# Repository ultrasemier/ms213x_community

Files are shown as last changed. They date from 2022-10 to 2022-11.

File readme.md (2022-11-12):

# MS2130 MS2131 Reference Design

## HardWare
  LCEDA

  MS2130
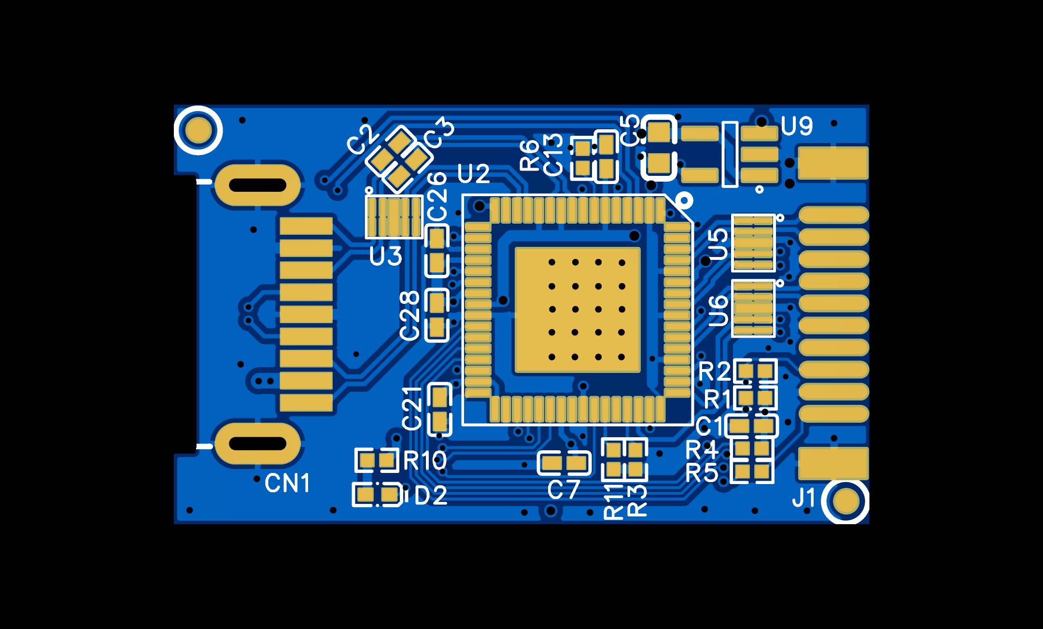
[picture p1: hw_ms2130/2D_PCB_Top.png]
MS2130 top
  
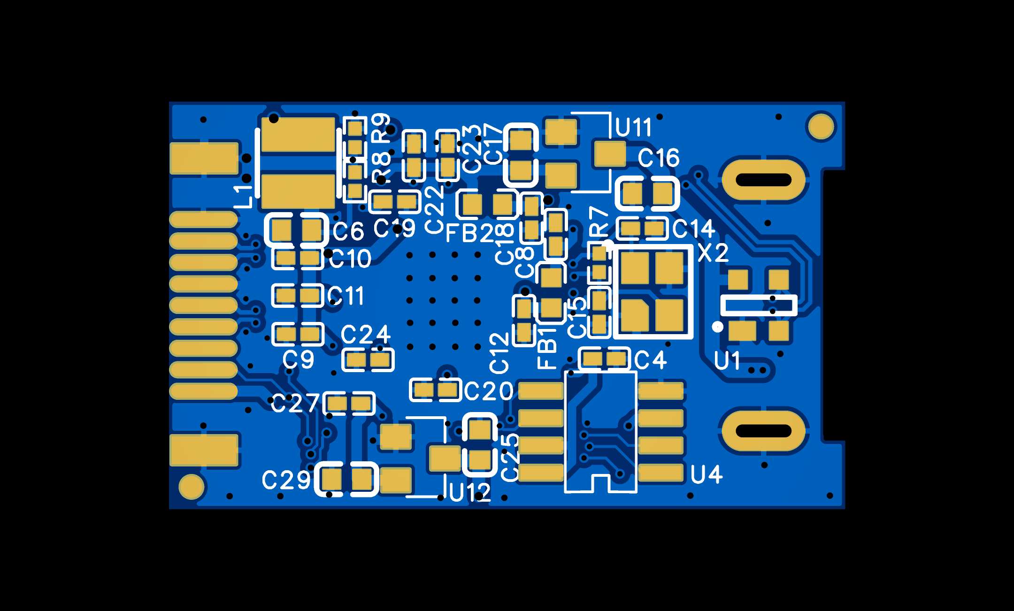
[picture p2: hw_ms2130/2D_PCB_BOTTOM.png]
MS2130 bottom
  
  MS2131
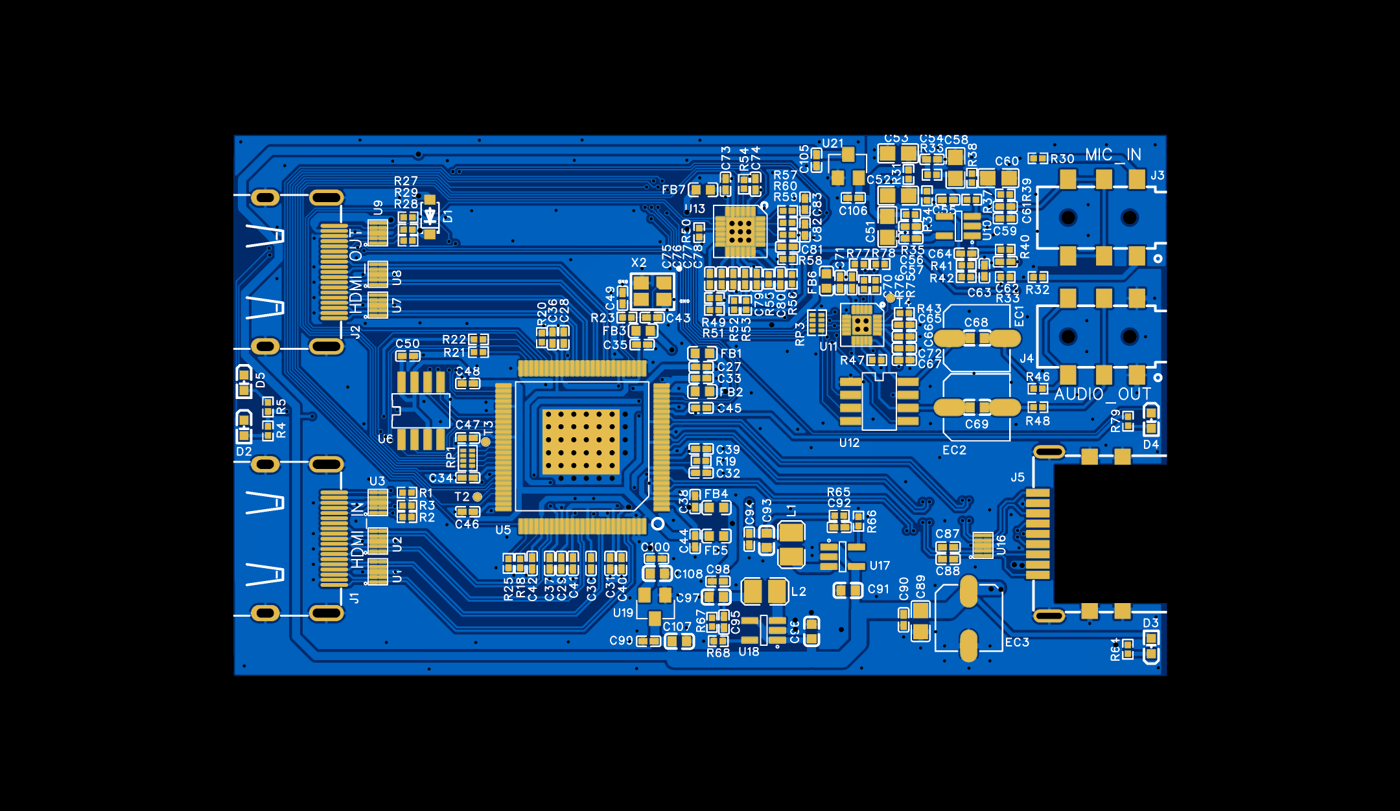
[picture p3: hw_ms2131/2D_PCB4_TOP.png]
MS2131 top
  
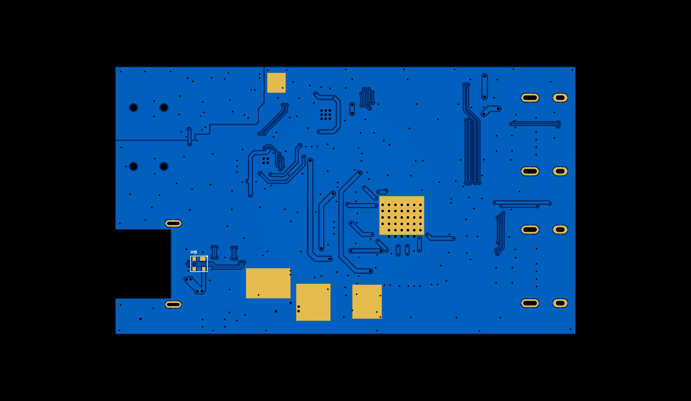
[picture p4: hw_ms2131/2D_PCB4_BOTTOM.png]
MS2131 bottom
  

## FirmWare
  [MS2130_sample_20221026](firmware/MS2130_sample_20221026.bin)
## Doc
  [MS2130 DS](doc/ms2130_ds.md)
## PCTool

## User Data

| ROM Address | Flash Address | Length  | User Data | data type |
|--- |--- |--- |--- | --- |
| 0x00F800 | 0x00F830 | 0x100 |edid | uint8 array[256] |
| 0x00F900 | 0x00F930 | 0x120 |hdcpUserKey | uint8 array[288] |
| 0x00FA20 | 0x00FA50 | 0x020 |ultrasemi | uchar array[32]  |
| 0x00FA40 | 0x00FA70 | 0x020 |ultrasemi_version | uchar array[32]  |
| 0x00FA60 | 0x00FA90 | 0x020 |ultrasemi_magic | uint8 array[32]  |
| 0x00FA80 | 0x00FAB0 | 0x020 |ManufacturerString  | user_string_t |
| 0x00FAA0 | 0x00FAD0 | 0x020 |ProduceString | user_string_t |
| 0x00FAC0 | 0x00FAF0 | 0x020 |U2ProduceString | user_string_t |
| 0x00FAE0 | 0x00FB10 | 0x020 |AudioString | user_string_t |
| 0x00FB00 | 0x00FB30 | 0x020 |U2AudioString | user_string_t |
| 0x00FB20 | 0x00FB50 | 0x020 |SerialnumString | user_string_t |
| 0x00FB40 | 0x00FB70 | 0x020 |U2SerialnumString | user_string_t |
| 0x00FB60 | 0x00FB90 | 0x020 |BCSH | user_bcsh_t |
| 0x00FB80 | 0x00FBB0 | 0x020 |AudioRoute | audio_route_t |

### user_string_t

* [Offset 0] length : uint8
  + 2 ~ 31
* [Offset 1:31] char array : uchar
  
### user_bcsh_t

  | Index | data type | data name |---              |
  |---    |---        |---        |---              |
  | 0     | UINT8     | bcsh_en   |0x01: User BCSH data Enable<br>other: User BCSH data Disable|
  | 1     | INT8      | b         | -127 ~ 128      |
  | 2     | UINT8     | c         | 0 ~ 255         |
  | 3     | UINT8     | s         | 0 ~ 255         |
  | 3     | INT8      | h         | -127 ~ 128      |
  
### audio_route_t

* [Offset 0] sample_rate : UINT8
  + 0 : AUDIO_SR_48000
  + 1 : AUDIO_SR_96000
  + other : Not used
* [Offset 1] i2s_in_mode : UINT8
  + 0 : slave
  + 1 : master
  + other : Not used
* [Offset 2] mix3_mode : UINT8
  + 1 : HDMI RX
  + 2 : I2S1 IN
  + 3 : I2S1 IN & HDMI RX
  + 4 : I2S2
  + 5 : I2S2 IN & HDMI RX
  + 6 : I2S1 IN & I2S2 IN
  + 7 : I2S1 IN & I2S2 IN & HDMI RX
  + other : Not used
* [Offset 3] i2s1_mode : UINT8
  + 9  : HDMI RX
  + 10 : MIX3 & USB OUT
  + 11 : MIX3
  + 12 : USB OUT
  + other : Not used
* [Offset 4] usb_out_mute : UINT8
  + 0 : unmute
  + 1 : mute
  + other : Not used
* [Offset 5] lk621_en : UINT8
  + 0x00 : none
  + 0x01 : config lk621 @0x26
  + 0x02 : config lk621 @0x20
  + 0x03 : config lk621 both
  + other : Not used

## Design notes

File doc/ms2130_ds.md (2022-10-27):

# MS2130 - USB3.0 高清视频采集芯片

## (非官方文档)

### 1.基本介绍

MS2130 是一款 USB 3.0 高清视频和音频采集芯片，内部集成 USB3.0 Device 控制器、数据收发模块、音视频处理模块。MS2130 可以通过 USB 3.0 接口将 HDMI 输入的音视频信号传送到 PC、智能手机、平板电脑上预览或采集。MS2130 输出支特 YUV422 和 MJPEG 两种模式，兼容 Windows、Android 和Mac OS 系统。

||MS2109|	MS2130|
|--- |---|---|
|USB  版本 |	2.0	|3.2 Gen1|
|USB 速率	 |480Mbps	|5Gbps|
|1080P@30 MJPEG	  |支持	|支持|
|1080P@60 MJPEG	  |不支持	|支持|
|1080P@30 YUV422	|不支持	|支持|
|1080P@60 YUV422	|不支持	|支持|
|典型延时	 |80ms	|50ms

### 2.功能特征

* HDMI RX
  * HDMI 1.4b 兼容
  * 支持 DVI 1.0
  * 支持 HDCP 1.4
  * 支持 RGB444、YCBCR422、YCBCR444、YCBCR420
  * 支持 deep color 24/30/36 位模式
  * 支持 CEA-861-E/CEA-861-F 视频格式
  * 最大输入分辨率 4K(3840×2160@30Hz)
  
* USB 3.0
  * 集成 USB 3.0 Device
  * 兼容 USB 2.0 Device 模式
  * USB 视频符合 UVC 1.0 协议
  * USB 音频符合 UAC 1.0 协议
  * USB 视频输出支持 YUV422 和 MJPEG 两种模式

* USB 视频输出分辨率
  * 默认最大分辨率1920×1080@60Hz
  
* 操作系统支持
  * Windows XP/7/8/10
  * Andriod 5.0 或以上
  * MacOS
  * Linux
  * 其他支持UVC的系统
  
* 时钟处理
  * 外接 24MHz 无源晶振
  * 内建 PLL 电路

* 复位
  * 内建上电复位电路

* 封装
  * QFN-64塑封（9mm×9mm)
  * 无铅，符合RoHS标准

### 3.功能框图

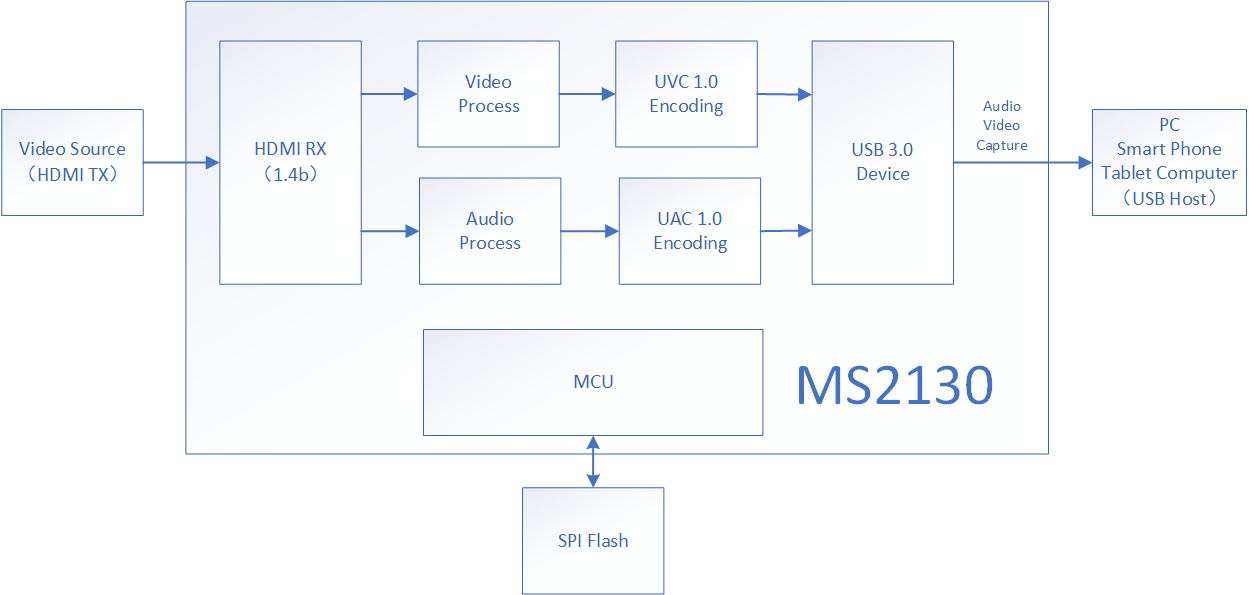
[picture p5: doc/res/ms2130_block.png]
  

### 4.功能描述

* **GPIO**
  
  MS2130有6个可编程GPIO,可通过软件自定义功能。

* **HDMI RX EDID描述**
  
  |类别|描述|
  |---|---|
  |显示名称|HDMI TO USB|
  |最佳分辨率1|4K@30Hz,297MHz|
  |最佳分辨率2|1080P@60Hz,148.5MHz|
  |视频支持分辨率列表|640×480@60Hz<br>800×600@60Hz<br>1024×768@60Hz<br>1152×864@60Hz<br>1280×720@60Hz<br>1280×800@60Hz<br>1280×960@60Hz<br>1280×1024@60Hz<br>1440×900@60Hz<br>1600×900@60Hz<br>1680×1050@60Hz<br>1920×1080@60Hz<br>3840×2160@30Hz<br>4096×2160@30Hz|
  |视频色彩空间支持|RGB,YUV444,LYUV422,YUV420|
  |Deep color支持| 30bits,36bits|
  |音频格式支持|格式：L-PCM<br>采样率：32KHz,44.1KHz,48KHz<br>通道数：最大两通道<br>位数：16bit,20bit,24bit

* **USB 视频输出**
  
  MS2130支持USB3.0&USB2.0模式视频采集，符合UVC1.0协议，支持YUV422和MJPEG两种格式视频输出，默认最大输出分辨率1920×1080@60Hz。
  MS2130USB默认输出分辨率列表如下，可以通过修改软件配置，由用户自定义输出分辨率(最大可支持到4K@15Hz)。

  <table>
    <tr>
      <td >USB 模式</td>
      <td>YUV422</td>
      <td>MJPEG</td>
    </tr>
    <tr>
      <td rowspan="11">USB 3.0 模式</td>
      <td>1920×1080@60Hz/50Hz/30Hz/20Hz/10Hz</td>
      <td>1920×1080@60HZ/50Hz/30Hz/20Hz/10Hz</td>
    </tr>
    <tr>
      <td>1600×1200@60Hz/50Hz/30Hz/20Hz/10Hz</td>
      <td>1600×1200@60Hz/50Hz/30Hz/20Hz/10Hz</td>
    </tr>
    <tr>
      <td>1360×  768@60Hz/50Hz/30Hz/20Hz/10Hz</td>
      <td>1360×  768@60Hz/50Hz/30Hz/20Hz/10Hz</td>
    </tr>
    <tr>
      <td>1280×1024@60Hz/50Hz/30Hz/20Hz/10Hz</td>
      <td>1280×1024@60Hz/50Hz/30Hz/20Hz/10Hz</td>
    </tr>
    <tr>
      <td>1280×  960@60Hz/50Hz/30Hz/20Hz/10Hz</td>
      <td>1280×  960@60Hz/50Hz/30Hz/20Hz/10Hz</td>
    </tr>
    <tr>
      <td>1280×  720@60Hz/50Hz/30Hz/20Hz/10Hz</td>
      <td>1280×  720@60Hz/50Hz/30Hz/20Hz/10Hz</td>
    </tr>
    <tr>
      <td>1024×  768@60Hz/50Hz/30Hz/20Hz/10Hz</td>
      <td>1024×  768@60Hz/50Hz/30Hz/20Hz/10Hz</td>
    </tr>
    <tr>
      <td>  800×  600@60Hz/50Hz/30Hz/20Hz/10Hz</td>
      <td>  800×  600@60Hz/50Hz/30Hz/20Hz/10Hz</td>
    </tr>
    <tr>
      <td>  720×  576@60Hz/50Hz/30Hz/20Hz/10Hz</td>
      <td>  720×  576@60Hz/50Hz/30Hz/20Hz/10Hz</td>
    </tr>
    <tr>
      <td>  720×  480@60Hz/50Hz/30Hz/20Hz/10Hz</td>
      <td>  720×  480@60Hz/50Hz/30Hz/20Hz/10Hz</td>
    </tr>
    <tr>
      <td>  640×  480@60Hz/50Hz/30Hz/20Hz/10Hz</td>
      <td>  640×  480@60Hz/50Hz/30Hz/20Hz/10Hz</td>
    </tr>
    <tr>
      <td rowspan="11">USB 2.0 模式</td>
      <td>1920×1080@10Hz/5Hz</td>
      <td>1920×1080@50Hz/30Hz/25Hz/20Hz/10Hz</td>
    </tr>
    <tr>
      <td>1600×1200@10Hz/5Hz</td>
      <td>1600×1200@60Hz/50Hz/30Hz/20Hz/10Hz</td>
    </tr>
    <tr>
      <td>1360×  768@15Hz/8Hz</td>
      <td>1360×  768@60Hz/50Hz/30Hz/20Hz/10Hz</td>
    </tr>
    <tr>
      <td>1280×1024@15Hz/8Hz</td>
      <td>1280×1024@60Hz/50Hz/30Hz/20Hz/10Hz</td>
    </tr>
    <tr>
      <td>1280×  960@15Hz/8Hz</td>
      <td>1280×  960@60Hz/50Hz/30Hz/20Hz/10Hz</td>
    </tr>
    <tr>
      <td>1024×  768@20Hz/10Hz</td>
      <td>1024×  768@60Hz/50Hz/30Hz/20Hz/10Hz</td>
    </tr>
    <tr>
      <td>  800×  600@30Hz/20Hz/10Hz</td>
      <td>  800×  600@60Hz/50Hz/30Hz/20Hz/10Hz</td>
    </tr>
    <tr>
      <td>  720×  576@60Hz/25Hz/20Hz/10Hz</td>
      <td>  720×  576@60Hz/50Hz/30Hz/20Hz/10Hz</td>
    </tr>
    <tr>
      <td>  720×  480@60Hz/30Hz/20Hz/10Hz</td>
      <td>  720×  480@60Hz/50Hz/30Hz/20Hz/10Hz</td>
    </tr>
    <tr>
      <td>  640×  480@60Hz/30Hz/20Hz/10Hz</td>
      <td>  640×  480@60Hz/50Hz/30Hz/20Hz/10Hz</td>
    </tr>
  </table>

* **USB 音频输出**
  
  MS2130 USB音频符合UAC1.0协议，默认输出为48KHz立体声，可通过软件配置实现其它分辨率音频输出。

### 5.引脚
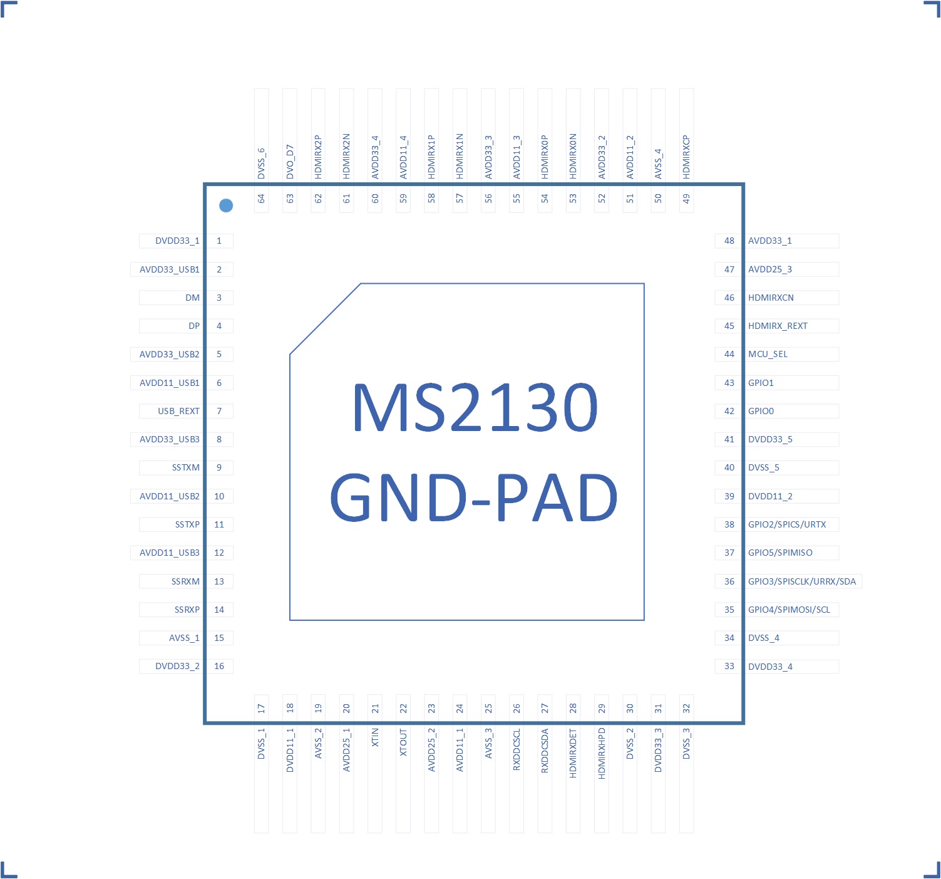
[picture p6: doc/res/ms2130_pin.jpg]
  

### 6.引脚描述

  <table>
    <tr>
      <td>引脚名称</td>
      <td>引脚#</td>
      <td>类型</td>
      <td>描述</td>
    </tr>
    <tr>
      <td colspan="4">通用IO</td>
    </tr>
    <tr>
      <td>GPIO0</td>
      <td>42</td>
      <td>数字输入/输出</td>
      <td>通用数字IO</td>
    </tr>
    <tr>
      <td>GPIO1</td>
      <td>43</td>
      <td>数字输入/输出</td>
      <td>通用数字IO</td>
    </tr>
    <tr>
      <td>GPIO2/SPICS/URTX</td>
      <td>38</td>
      <td>数字输入/输出</td>
      <td>通用数字IO,复用SPI Master接口CSPN和UART TX PIN;<br>如果外围连接了SPI接口Flash,芯片上电后会自动配置为SPICS功能</td>
    </tr>
    <tr>
      <td>GPIO3/SPISCLK/URRX/SDA</td>
      <td>36</td>
      <td>数字输入/输出</td>
      <td>通用数字IO,复用SPI Master接口SCLK PIN、UART RX PIN和I2C Master SDA PIN;<br>如果外围连接了SPI接口Flash,芯片上电后会自动配置为SPISCLK功能</td>
    </tr>
    <tr>
      <td>GPIO4/SPIMOSI/SCL</td>
      <td>35</td>
      <td>数字输入/输出</td>
      <td>通用数字IO,复用SPI Master接口MOSI PIN和I2C Master SCL PIN;<br>如果外围连接了SPI接口Flash,芯片上电后会自动配置为SPIMOSI功能</td>
    </tr>
    <tr>
      <td>GPIO5/SPIMISO</td>
      <td>37</td>
      <td>数字输入/输出</td>
      <td>通用数字IO,复用SPI Master接口MISO PIN;<br>如果外围连接了SPI接口Flash,芯片上电后会自动配置为SPI MISO功能</td>
    </tr>
    <tr>
      <td colspan="4">USB</td>
    </tr>
    <tr>
      <td>DP</td>
      <td>4</td>
      <td>数字输入/输出</td>
      <td>USB2.0差分正端信号</td>
    </tr>
    <tr>
      <td>DM</td>
      <td>3</td>
      <td>数字输入/输出</td>
      <td>USB2.0差分负端信号</td>
    </tr>
    <tr>
      <td>USB REXT</td>
      <td>7</td>
      <td>数字输出</td>
      <td>接200欧电阻到地</td>
    </tr>
    <tr>
      <td>SSTXP</td>
      <td>11</td>
      <td>数字输出</td>
      <td>USB3.0差分输出正端信号</td>
    </tr>
    <tr>
      <td>SSTXM</td>
      <td>9</td>
      <td>数字输出</td>
      <td>USB3.0差分输出负端信号</td>
    </tr>
    <tr>
      <td>SSRXP</td>
      <td>14</td>
      <td>数字输入</td>
      <td>USB3.0差分输入正端信号</td>
    </tr>
    <tr>
      <td>SSRXM</td>
      <td>13</td>
      <td>数字输入</td>
      <td>USB3.0差分输入负端信号</td>
    </tr>
    <tr>
      <td colspan="4">HDMI RX</td>
    </tr>
    <tr>
      <td>HDMIRXCN</td>
      <td>46</td>
      <td>数字输入</td>
      <td>HDMI接收端差分时钟输入负端信号</td>
    </tr>
    <tr>
      <td>HDMIRXCP</td>
      <td>49</td>
      <td>数字输入</td>
      <td>HDMI接收端差分时钟输入正端信号</td>
    </tr>
    <tr>
      <td>HDMIRX0N</td>
      <td>53</td>
      <td>数字输入</td>
      <td>HDMI接收端差分通道0数据输入负端信号</td>
    </tr>
    <tr>
      <td>HDMIRX0P</td>
      <td>54</td>
      <td>数字输入</td>
      <td>HDMI接收端差分通道0数据输入正端信号</td>
    </tr>
    <tr>
      <td>HDMIRX1N</td>
      <td>57</td>
      <td>数字输入</td>
      <td>HDMI接收端差分通道1数据输入负端信号</td>
    </tr>
    <tr>
      <td>HDMIRX1P</td>
      <td>58</td>
      <td>数字输入</td>
      <td>HDMI接收端差分通道1数据输入正端信号</td>
    </tr>
    <tr>
      <td>HDMIRX2N</td>
      <td>61</td>
      <td>数字输入</td>
      <td>HDMI接收端差分通道2数据输入负端信号</td>
    </tr>
    <tr>
      <td>HDMIRX2P</td>
      <td>62</td>
      <td>数字输入</td>
      <td>HDMI接收端差分通道2数据输入正端信号</td>
    </tr>
    <tr>
      <td>HDMIRX_REXT</td>
      <td>45</td>
      <td>模拟输出</td>
      <td>连接一个1.6k电阻到地</td>
    </tr>
    <tr>
      <td>HDMIRXHPD</td>
      <td>29</td>
      <td>数字输出</td>
      <td>HDMI接收端热插拔信号输出</td>
    </tr>
    <tr>
      <td>HDMIRXDET</td>
      <td>28</td>
      <td>数字输入</td>
      <td>HDMI接收端5V输入检测</td>
    </tr>
    <tr>
      <td>RXDDCSDA</td>
      <td>27</td>
      <td>数字输入/输出</td>
      <td>HDMI接收端显示数据通道串行数据总线</td>
    </tr>
    <tr>
      <td>RXDDCSCL</td>
      <td>26</td>
      <td>数字输入</td>
      <td>HDMI接收端显示数据通道串行时钟总线</td>
    </tr>
    <tr>
      <td colspan = "4">调试 PIN</td>
    </tr>
    <tr>
      <td>MCU_SEL</td>
      <td>44</td>
      <td>数字输入</td>
      <td>调试PIN，默认浮空</td>
    </tr>
    <tr>
      <td>DVO_D7</td>
      <td>63</td>
      <td>数字输出</td>
      <td>调试PIN，默认浮空</td>
    </tr>
    <tr>
      <td colspan="4">晶振</td>
    </tr>
    <tr>
      <td>XTIN</td>
      <td>21</td>
      <td>模拟输入</td>
      <td>接24MHz无源晶振输入</td>
    </tr>
    <tr>
      <td>XTOUT</td>
      <td>22</td>
      <td>模拟输出</td>
      <td>接24MHz无源晶振输出</td>
    </tr>
    <tr>
      <td colspan = "4">系统电源和地</td>
    </tr>
    <tr>
      <td>AVDD33_USB1~3</td>
      <td>2,5,8</td>
      <td>电源</td>
      <td>USB模块3.3V供电</td>
    </tr>
    <tr>
      <td>AVDD33_1~4</td>
      <td>48,52,56,60</td>
      <td>电源</td>
      <td>模拟3.3V供电</td>
    </tr>
    <tr>
      <td>DVDD33_1~5</td>
      <td>1,16,31,33,41</td>
      <td>电源</td>
      <td>数字 IO 3.3V供电</td>
    </tr>
    <tr>
      <td>AVDD25_1~3</td>
      <td>20,23,47</td>
      <td>电源</td>
      <td>模拟2.5V供电</td>
    </tr>
    <tr>
      <td>AVDD11_USB1~3</td>
      <td>6,10,12</td>
      <td>电源</td>
      <td>USB模块1.1V供电</td>
    </tr>
    <tr>
      <td>DVD11_1~2</td>
      <td>18,39</td>
      <td>电源</td>
      <td>数字1.1V供电</td>
    </tr>
    <tr>
      <td>AVD11_1~4</td>
      <td>24,51,55,59</td>
      <td>电源</td>
      <td>模拟1.1V供电</td>
    </tr>
    <tr>
      <td>AVSS_1~4</td>
      <td>15,19,25,50</td>
      <td>地</td>
      <td>模拟地</td>
    </tr>
    <tr>
      <td>DVSS_1~6</td>
      <td>17,30,32,34,40,64</td>
      <td>地</td>
      <td>数字地</td>
    </tr>
    <tr>
      <td>GND-PAD</td>
      <td> </td>
      <td>地</td>
      <td>接模拟地</td>
    </tr>
  </table>

### 7.功耗

  * **不同工作状态的功耗**

    测试条件：地=0V,温度25C。
    <table>
      <tr>
        <td>参数</td>
        <td>UVC ON<br>输入1080P@60Hz<br>输出1080P(@60Hz</td>
        <td>UVC OFF<br>HDMI 不接</td>
        <td>USB休眠</td>
        <td>单位</td>
      </tr>
      <tr>
        <td>VDD33</td>
        <td>0.389</td>
        <td>0.049</td>
        <td>0.019</td>
        <td>瓦</td>
      </tr>
      <tr>
        <td>VDD25</td>
        <td>0.077</td>
        <td>0.01</td>
        <td>0.005</td>
        <td>瓦</td>
      </tr>
      <tr>
        <td>VDD11</td>
        <td>0.146</td>
        <td>0.055</td>
        <td>0.012</td>
        <td>瓦</td>
      </tr>
    </table>

  * **不同模式的电流**

    USB输入固定为1920x1080@60Hz,YUV模式，不同输入模式电流典型值.测试条件:地=0V,温度=+25C。
    
    <table>
      <tr>
        <td>参数</td>
        <td>4K@30Hz</td>
        <td>1080P@60Hz</td>
        <td>720P@60Hz</td>
        <td>单位</td>
      </tr>
      <tr>
        <td>AVDD33</td>
        <td>107</td>
        <td>93</td>
        <td>79</td>
        <td>毫安</td>
      </tr>
      <tr>
        <td>DVDD33</td>
        <td>28</td>
        <td>31</td>
        <td>22</td>
        <td>毫安</td>
      </tr>
      <tr>
        <td>AVDD25</td>
        <td>31</td>
        <td>30</td>
        <td>19</td>
        <td>毫安</td>
      </tr>      
      <tr>
        <td>AVDD11</td>
        <td>96</td>
        <td>80</td>
        <td>70</td>
        <td>毫安</td>
      </tr>      
      <tr>
        <td>DVDD11</td>
        <td>74</td>
        <td>66</td>
        <td>58</td>
        <td>毫安</td>
      </tr>
    </table>

### 8.封装

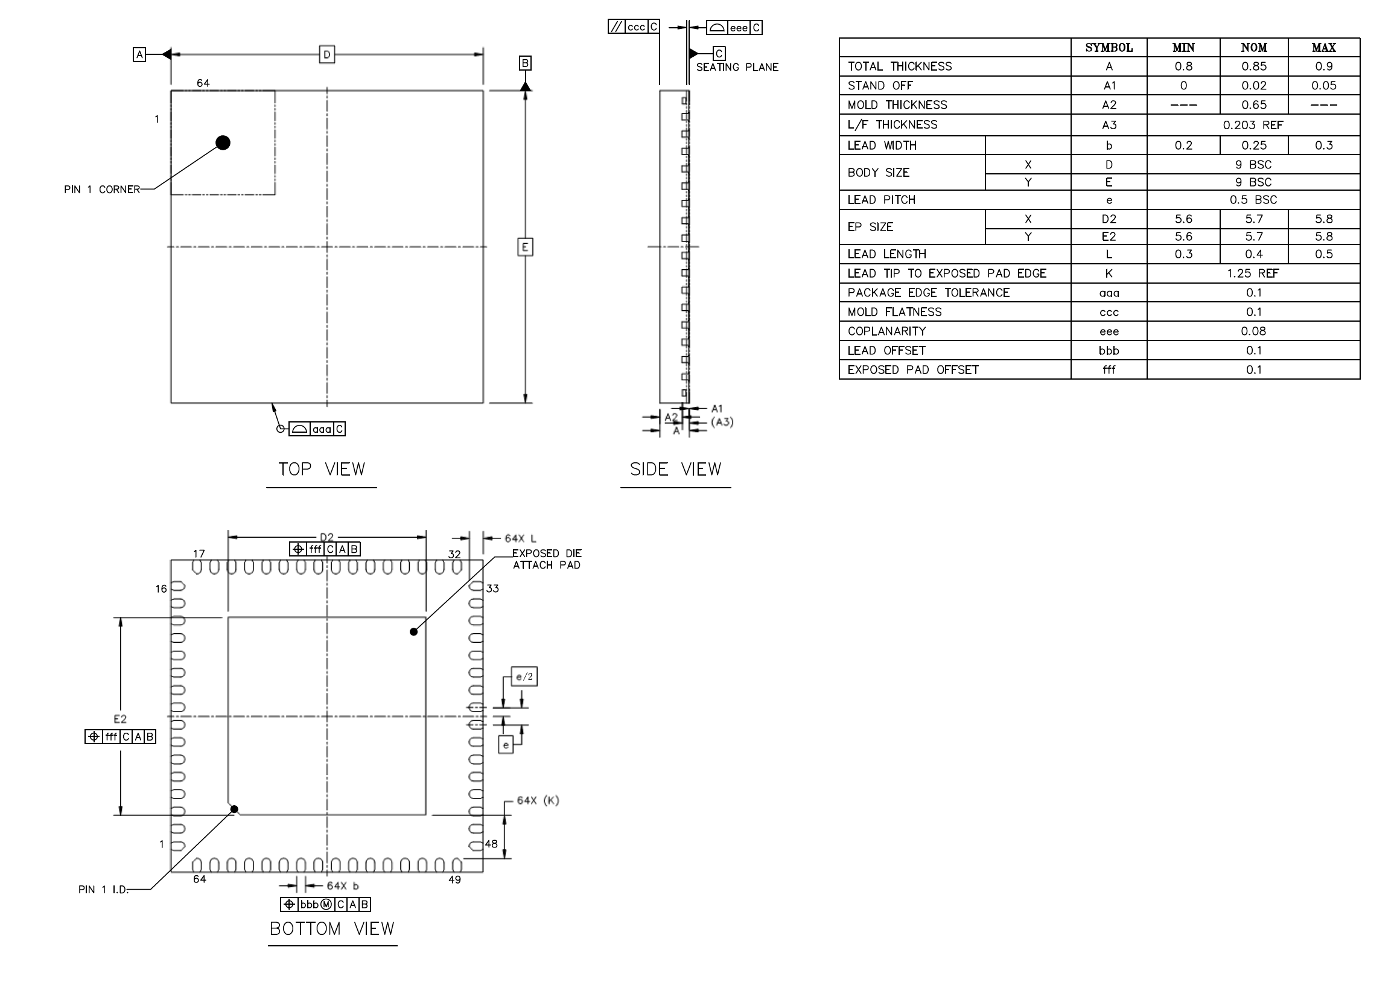
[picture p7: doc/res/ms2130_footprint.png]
封装
  

### 9.包装信息

  <table>
    <tr>
      <td>封装外形</td>
      <td>每TRAY盘数量<br>(单位：PCS)</td>
      <td>每内箱数量<br>(单位：PCS)</td>
      <td>每外箱数量<br>(单位：PCS)</td>
      <td>内外箱数比</td>
    </tr>
    <tr>
      <td>QFN64(9X9)</td>
      <td>260</td>
      <td>2600</td>
      <td>715600</td>
      <td>6:1</td>
    </tr>
  </table>

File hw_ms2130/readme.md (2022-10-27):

# MS2130 Hardware

## LCEDA

  [MS2130_HDMI2USB_DEMO_2022-10-27.zip](MS2130_HDMI2USB_DEMO_2022-10-27.zip)

## preview

2D_PCB_Top
2D_PCB_Top

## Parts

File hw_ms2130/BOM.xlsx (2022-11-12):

No. | Quantity | Designator | Footprint | Value
1 | 21 | C1,C2,C3,C4,C7,C8,C9,C10,C11,C12,C13,C18,C19,C20,C21,C22,C23,C24,C26,C27,C28 | C0402 | 100nF
2 | 6 | C5,C6,C16,C17,C25,C29 | C0603 | 10uF
3 | 2 | C14,C15 | C0402 | 22pF
4 | 1 | CN1 | USB3.0-A-SMD_U237-091N-4BLVS10-1 | USB3.0_male
5 | 1 | D2 | LED0402-RD_GREEN | LED-Green_SMD
6 | 2 | FB1,FB2 | L0603 | 30R/100MHz
7 | 1 | J1 | HDMI_A | HDMI-A
8 | 1 | L1 | IND-SMD_L3.0-W3.0 | 2.2uH
9 | 4 | M5,M6,M7,M8 | MARK | Mark
10 | 2 | R1,R2 | R0402 | 47K/5%
11 | 1 | R3 | R0402 | 1.6K/1%
12 | 2 | R4,R5 | R0402 | 1K/5%
13 | 1 | R6 | R0402 | 200R/1%
14 | 1 | R7 | R0402 | 1M/5%
15 | 1 | R8 | R0402 | 41.2K/1%
16 | 1 | R9 | R0402 | 47K/1%
17 | 1 | R10 | R0402 | 1.6K/5%
18 | 1 | R11 | R0402 | 0R/5%/NC
19 | 1 | U1 | SOT-143-4_L2.9-W1.3-P1.90-LS2.4-BL | PRTR5V0U2X
20 | 1 | U2 | QFN64-9X9X0.5 | MS2130
21 | 1 | U3 | SPL2510P8 | ULC0544P10
22 | 1 | U4 | SOIC8-1.27-150MIL | W25Q40
23 | 2 | U5,U6 | SPL2510P8 | RClamp0524P
24 | 1 | U9 | SOT-23-5 | TD6810-ADJ
25 | 1 | U11 | SOT-23 | XC6206P33
26 | 1 | U12 | SOT-23 | XC6206P25
27 | 1 | X2 | SMD-3225_4P_L3.2-W2.5 | 24MHz

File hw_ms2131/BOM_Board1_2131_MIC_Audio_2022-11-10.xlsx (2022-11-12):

No. | Quantity | Designator | Footprint | Value
1 | 35 | C27,C28,C29,C30,C31,C32,C33,C34,C35,C36,C37,C38,C39,C40,C41,C42,C44,C45,C46,C47,C48,C50,C54,C55,C56,C57,C71,C72,C73,C74,C87,C88,C90,C94,C98 | C0402 | 100nF
2 | 4 | C43,C49,C92,C95 | C0402 | 22pF
3 | 6 | C51,C52,C53,C58,C60,C89 | C0805 | 22uF
4 | 1 | C59 | C0402 | 330nF
5 | 1 | C61 | C0402 | 33pF/NC
6 | 1 | C62 | C0402 | 150pF/NC
7 | 4 | C63,C65,C66,C67 | C0402 | 4.7uF
8 | 1 | C64 | C0402 | 120pF
9 | 8 | C68,C69,C91,C93,C96,C97,C107,C108 | C0603 | 10uF
10 | 10 | C70,C76,C77,C78,C79,C80,C99,C100,C105,C106 | C0402 | 1uF
11 | 2 | C75,C81 | C0402 | 1uF/NC
12 | 2 | C82,C83 | C0402 | 20pF
13 | 1 | D1 | SOD-123_L2.6-W1.6-LS3.5-RD | STPS0520Z
14 | 3 | D2,D4,D5 | LED0603_L1.6-W0.8-RD_BLUE | LED_Green_SMD
15 | 1 | D3 | LED0603_L1.6-W0.8-RD_BLUE | LED_Red_SMD
16 | 2 | EC1,EC2 | 贴片电解电容6.3*5.4 | 100uF/35V/NC
17 | 1 | EC3 | 贴片电解电容6.3*5.4 | 100uF/35V
18 | 7 | FB1,FB2,FB3,FB4,FB5,FB6,FB7 | L0603 | 30R/100MHz
19 | 2 | J1,J2 | HDMI-SMD_19P-P0.50-H_HYC10-HDMI19-600B | HDMI
20 | 2 | J3,J4 | AUDIO-SMD_PJ313D | PJ-313D
21 | 1 | J5 | USB-3.0-SMD_HC-ST-003-008-J | USB3.0_F
22 | 2 | L1,L2 | L2520 | 2.2uH
23 | 3 | R1,R27,R41 | R0402 | 10K/5%
24 | 2 | R2,R3 | R0402 | 47K/5%
25 | 5 | R4,R5,R28,R29,R79 | R0402 | 2K/5%
26 | 2 | R18,R20 | R0402 | 1.6K/1%
27 | 1 | R19 | R0402 | 200R/1%
28 | 7 | R21,R22,R42,R52,R53,R59,R64 | R0402 | 1K/5%
29 | 1 | R23 | R0402 | 1M/5%
30 | 9 | R30,R32,R33,R35,R36,R43,R47,R50,R55 | R0402 | 0R/5%
31 | 4 | R31,R34,R37,R54 | R0402 | 100K/5%
32 | 2 | R38,R39 | R0402 | 2.2K/5%
33 | 3 | R40,R57,R60 | R0402 | 100R/5%
34 | 2 | R46,R48 | R0402 | 4.7R/5%
35 | 2 | R49,R58 | R0402 | 1K/5%/NC
36 | 2 | R51,R56 | R0402 | 2K/5%/NC
37 | 1 | R65 | R0402 | 41.2K/1%
38 | 1 | R66 | R0402 | 47K/1%
39 | 1 | R67 | R0402 | 680K/1%
40 | 1 | R68 | R0402 | 150K/1%
41 | 3 | R25,R75,R76 | R0402 | 0R/5%/NC
42 | 2 | R77,R78 | R0402 | 10K
43 | 2 | RP1,RP3 | 网络排阻0402x4 | 8P4R_33R
44 | 3 | T2,T3,T4 | 0.65MM_POINT | Test_Point
45 | 3 | U1,U2,U3 | SPL2510P8 | RCLamp0524P
46 | 1 | U5 | QFP100-0.5 | MS2131
47 | 1 | U6 | SOIC8-1.27-150MIL | W25Q40
48 | 3 | U7,U8,U9 | SPL2510P8 | RClamp0524P
49 | 1 | U10 | SOT-23-5 | S7001XF
50 | 1 | U11 | QFN20-0.4 | ES8156
51 | 1 | U12 | SOIC8-1.27-150MIL | MS7124/NC
52 | 1 | U13 | QFN24-0.5 | LK621
53 | 1 | U15 | SOT143B | PRTR5V0U2X
54 | 1 | U16 | SPL2510P8 | ULC0544P10
55 | 2 | U17,U18 | SOT-23-5 | TD6810-ADJ
56 | 1 | U19 | SOT-23 | XC6206P25
57 | 1 | U21 | SOT-23 | 6206-33GC
58 | 1 | X2 | SMD-3225_4P_C3SB40.000F15E12 | 24MHz

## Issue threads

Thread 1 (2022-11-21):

Black line on top

matiaspl, 2022-11-21:
The firmware currently available on github seems to suffer from an off-by-one error - the topmost first line of the captured video is totally black and the last at the bottom is truncated.

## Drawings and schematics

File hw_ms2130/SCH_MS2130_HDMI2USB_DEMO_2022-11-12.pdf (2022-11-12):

USB3.0 | HDMI RX | MS2130

# GND¹⁰⁰nF C¹

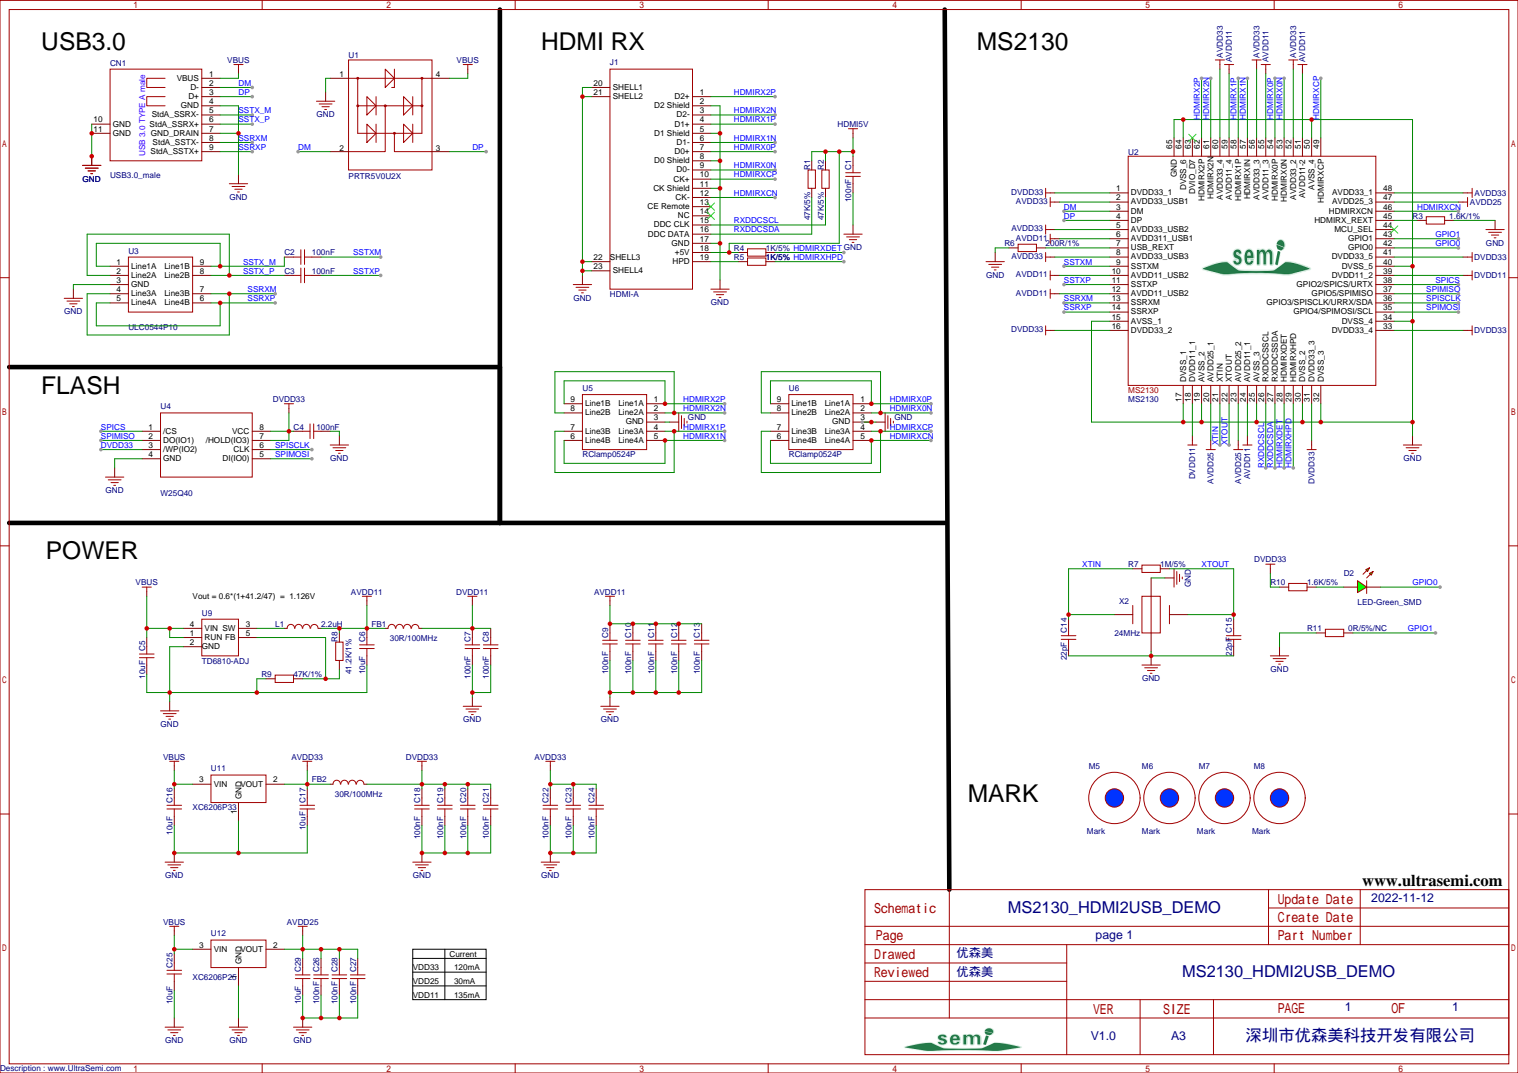
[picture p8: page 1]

Description : www.UltraSemi.com

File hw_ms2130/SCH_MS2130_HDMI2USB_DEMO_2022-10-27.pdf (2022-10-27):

USB3.0 | HDMI RX | MS2130

# GND¹⁰⁰nF C¹

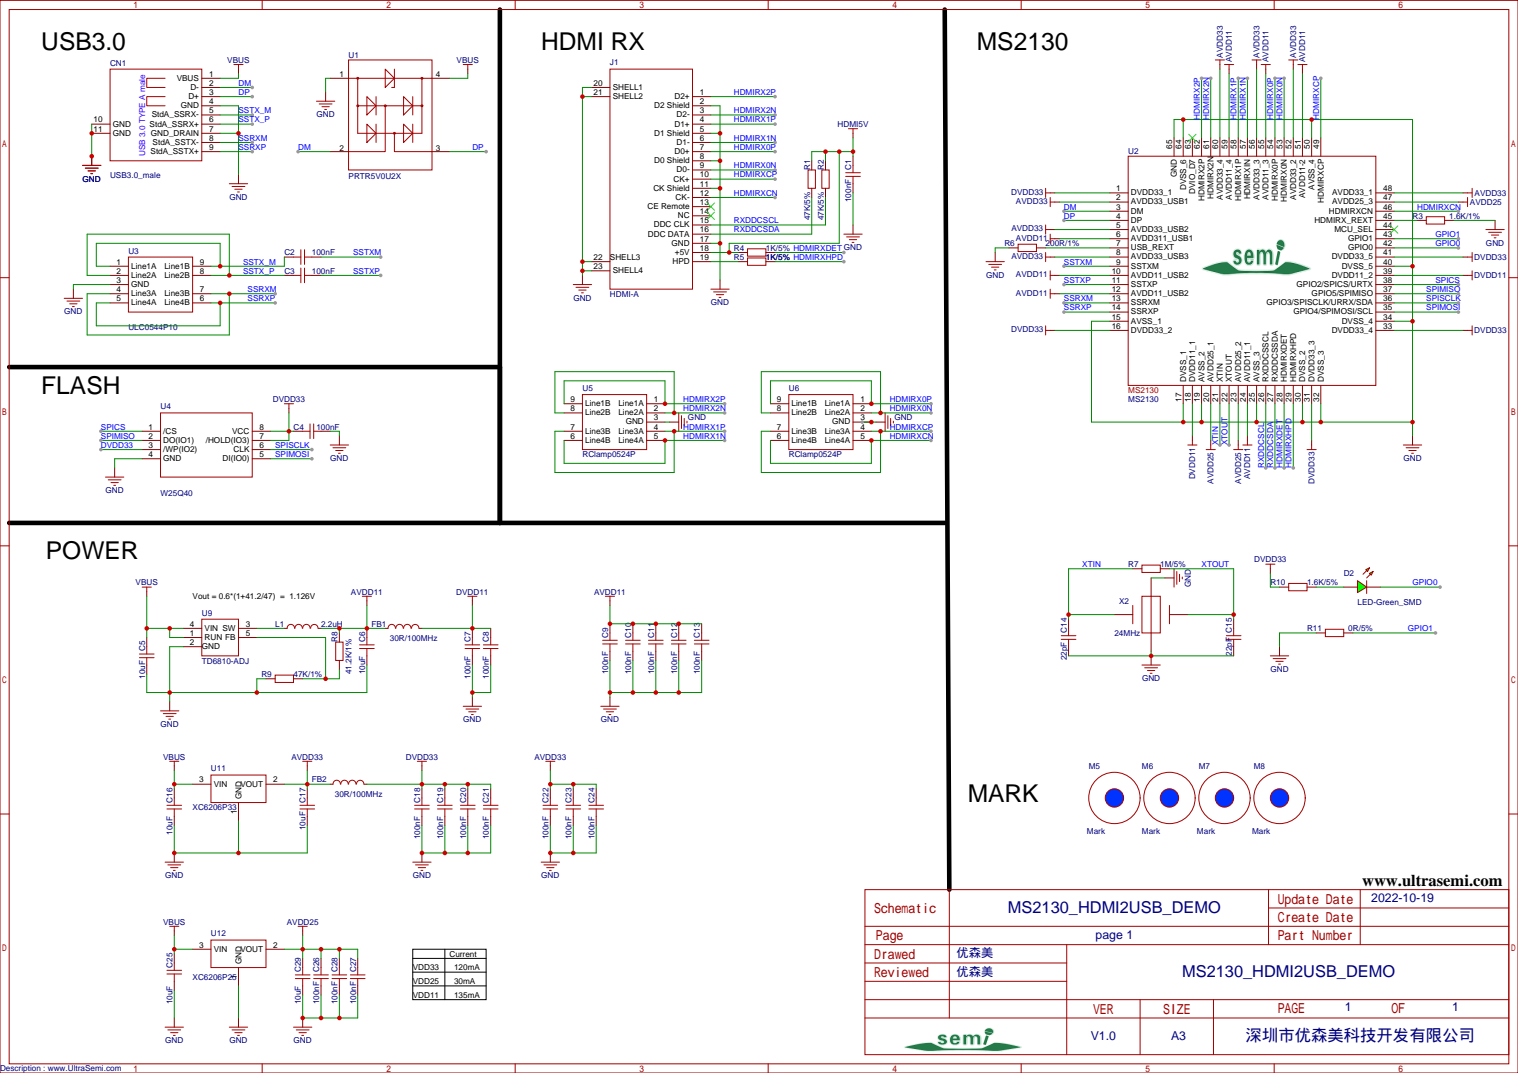
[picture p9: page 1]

Description : www.UltraSemi.com

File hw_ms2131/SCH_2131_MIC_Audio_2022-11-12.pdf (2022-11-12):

# HDMI_IN

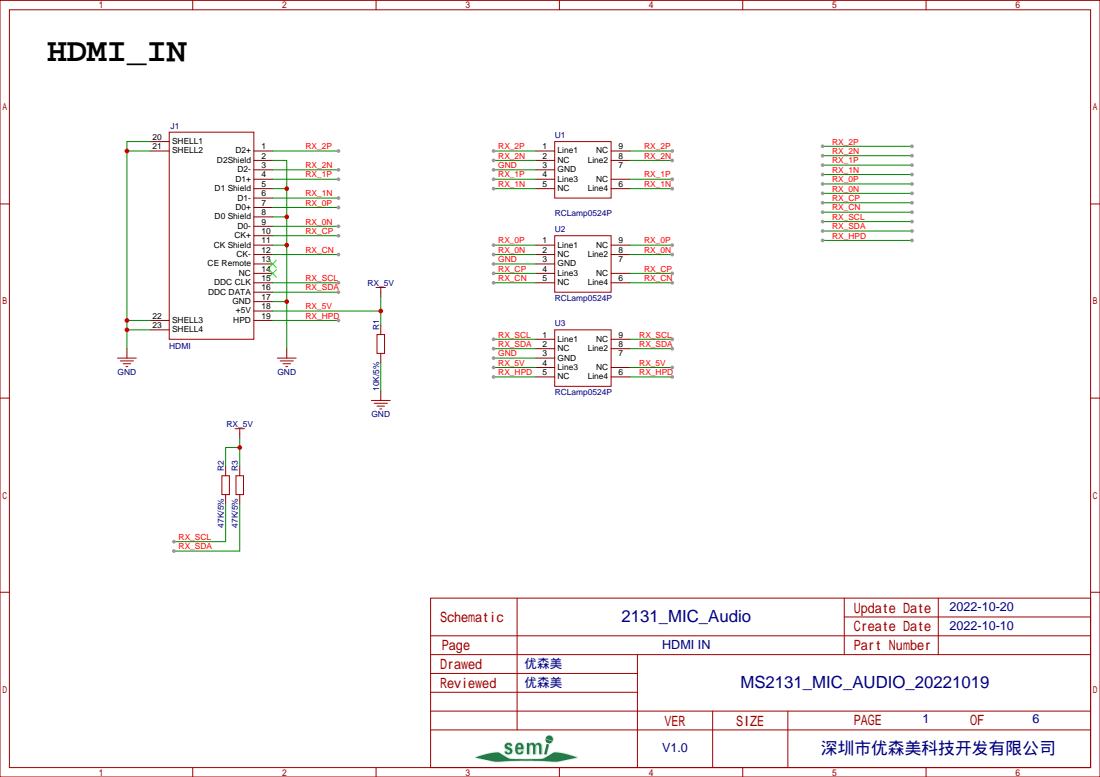
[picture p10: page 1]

MS2131

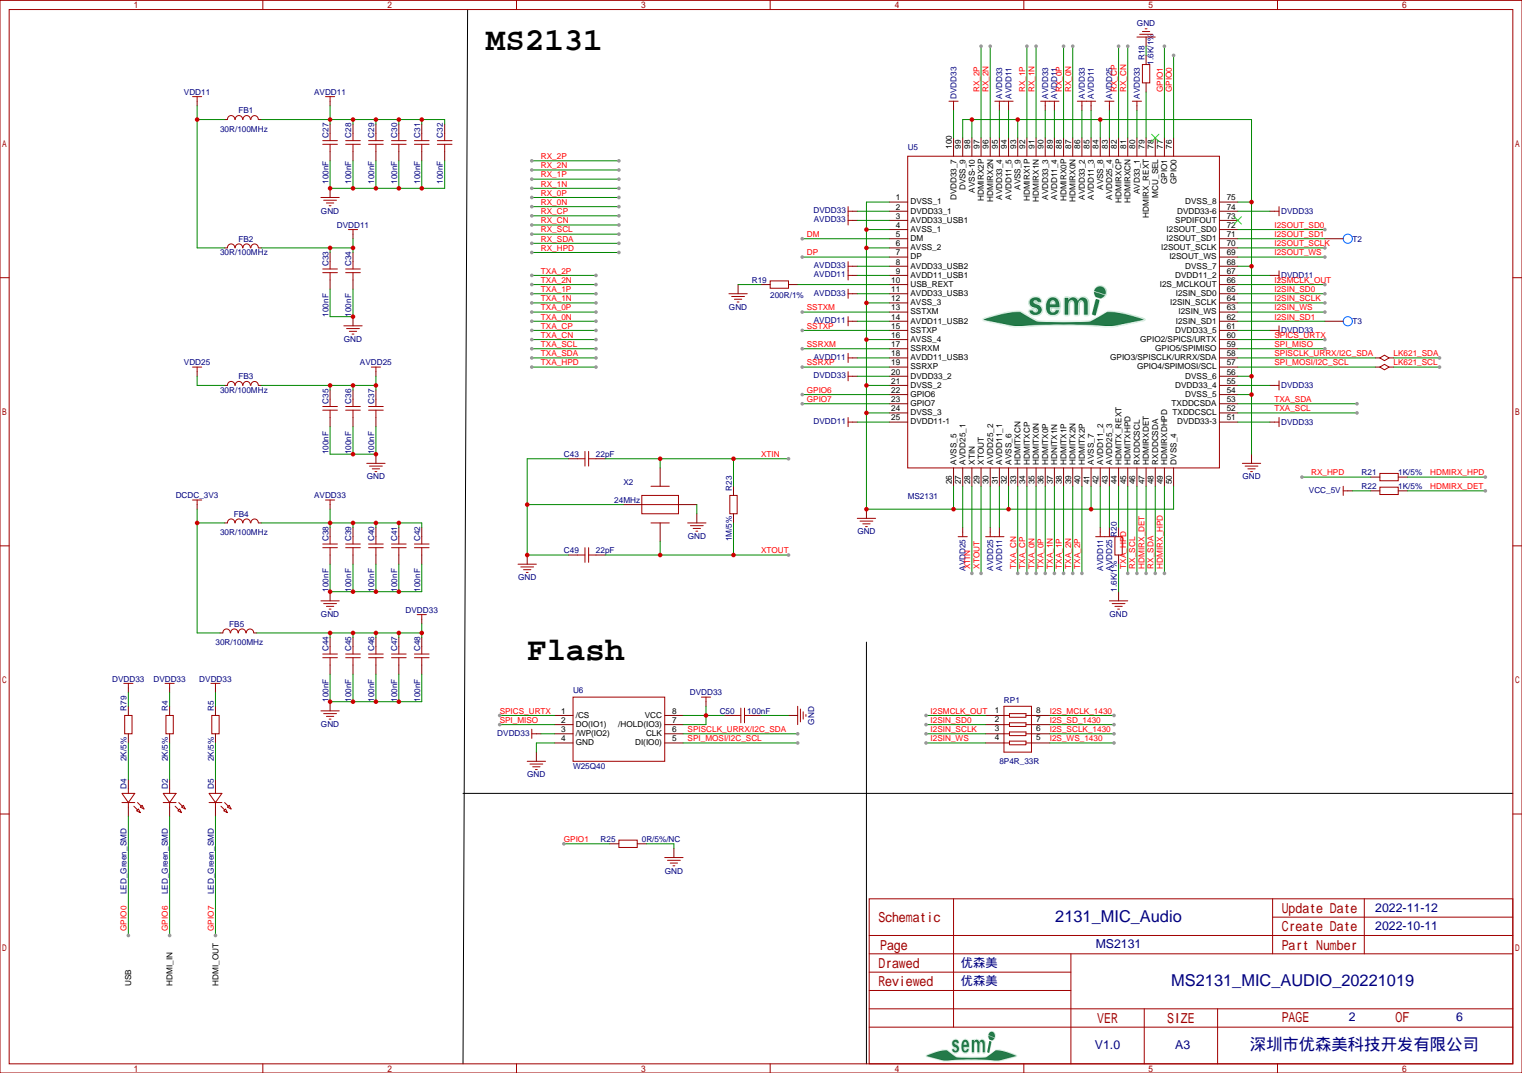
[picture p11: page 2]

# HDMI_OUT_B

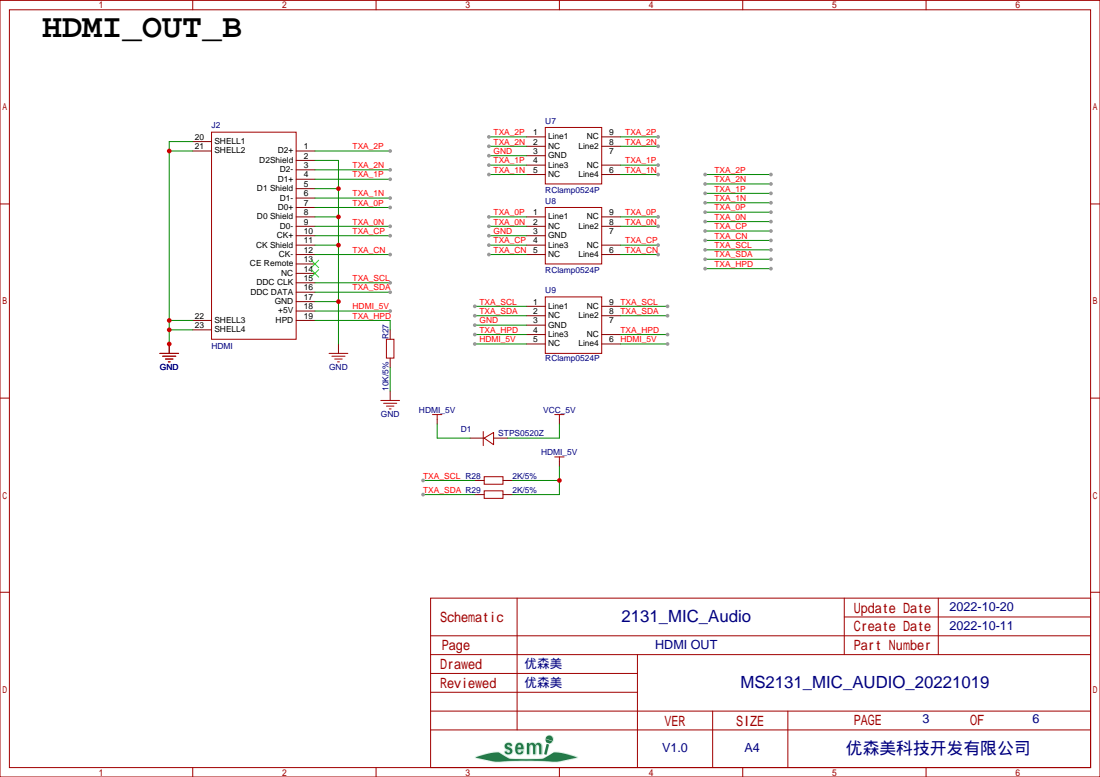
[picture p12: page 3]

# VCC33_MIC 100K/5% R³¹

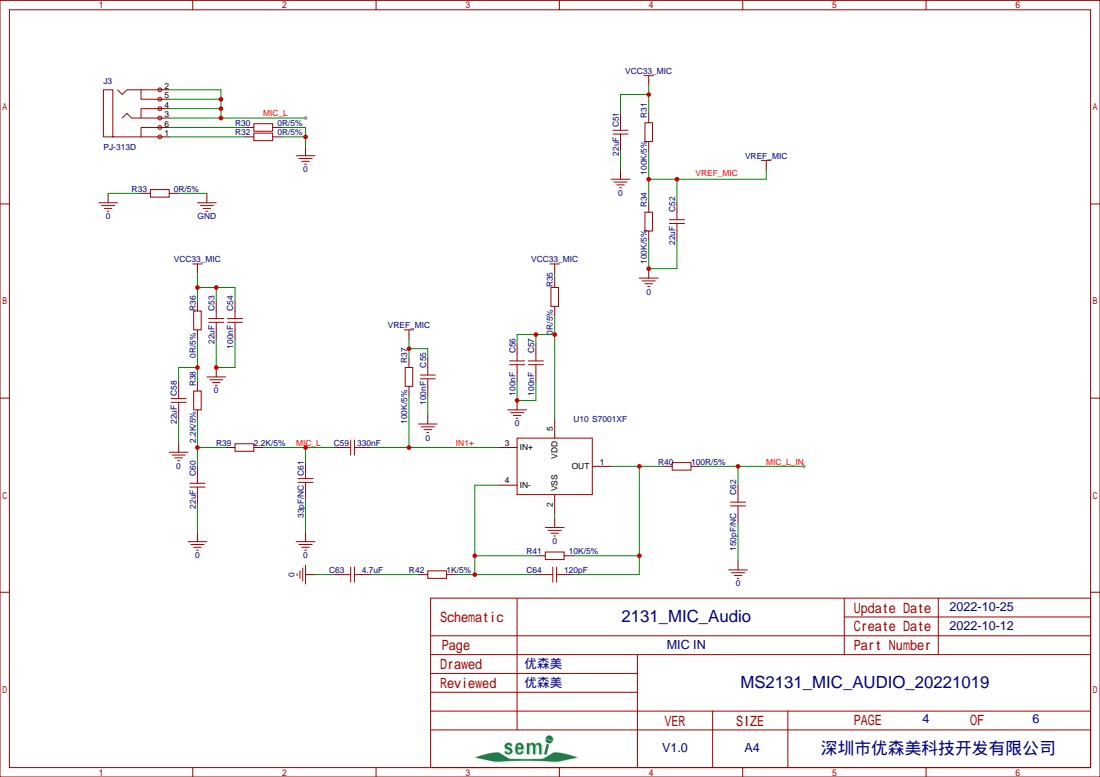
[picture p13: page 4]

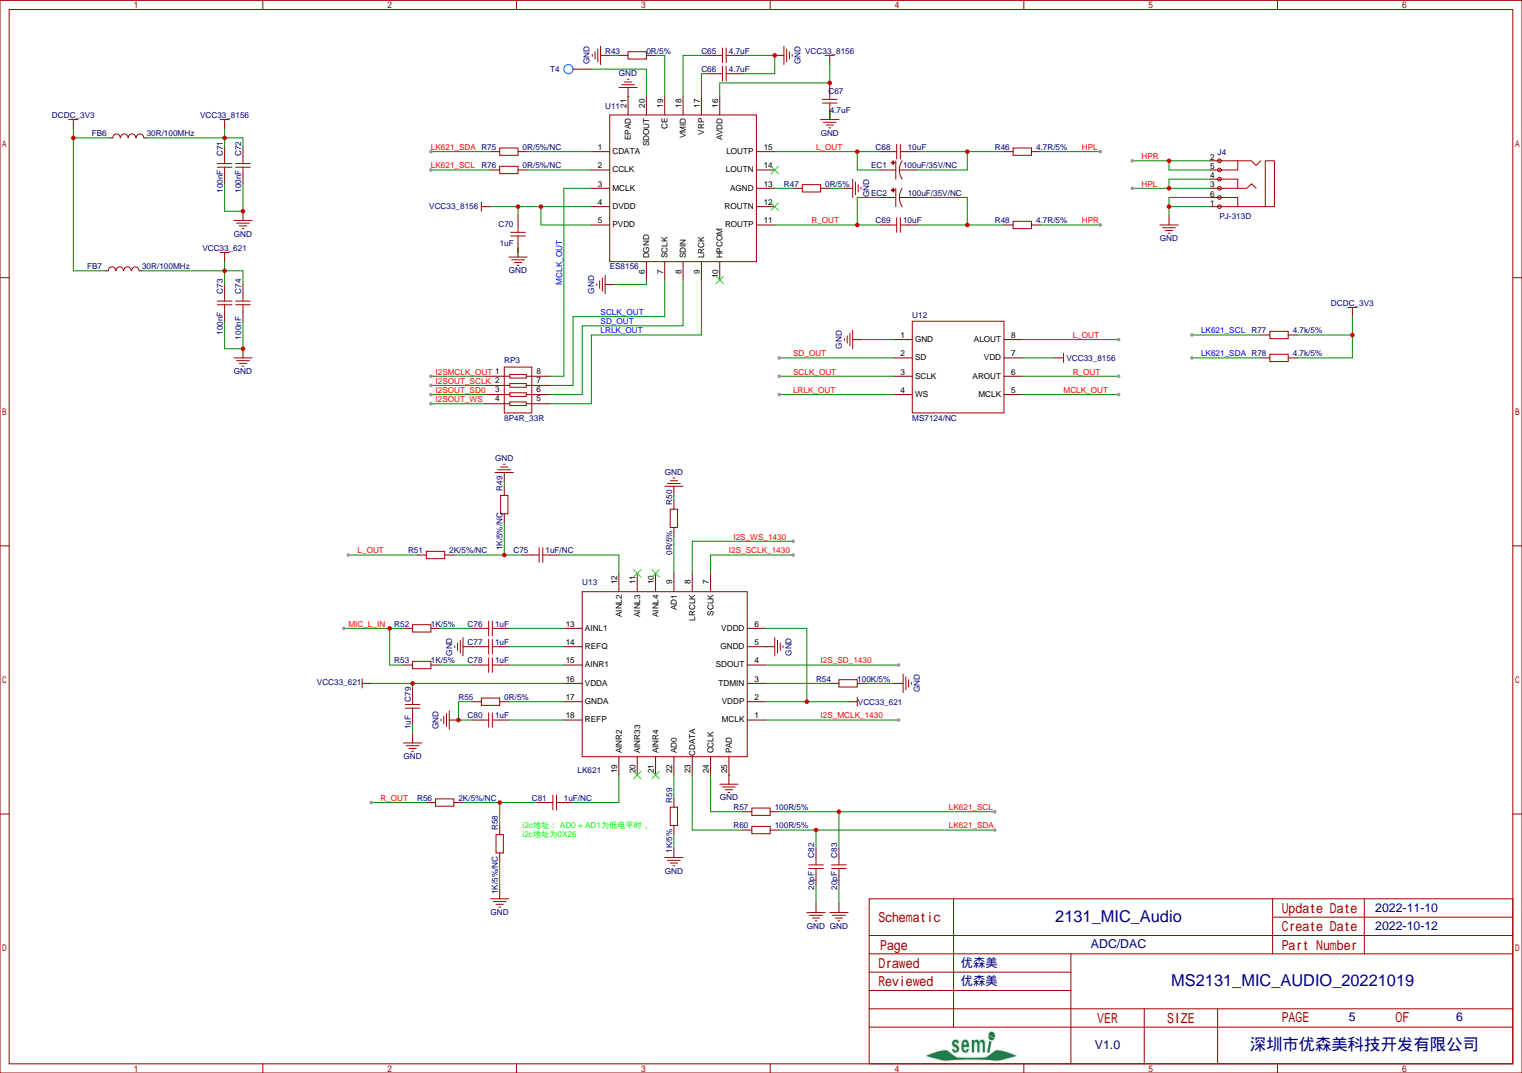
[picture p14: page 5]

# USB3.0

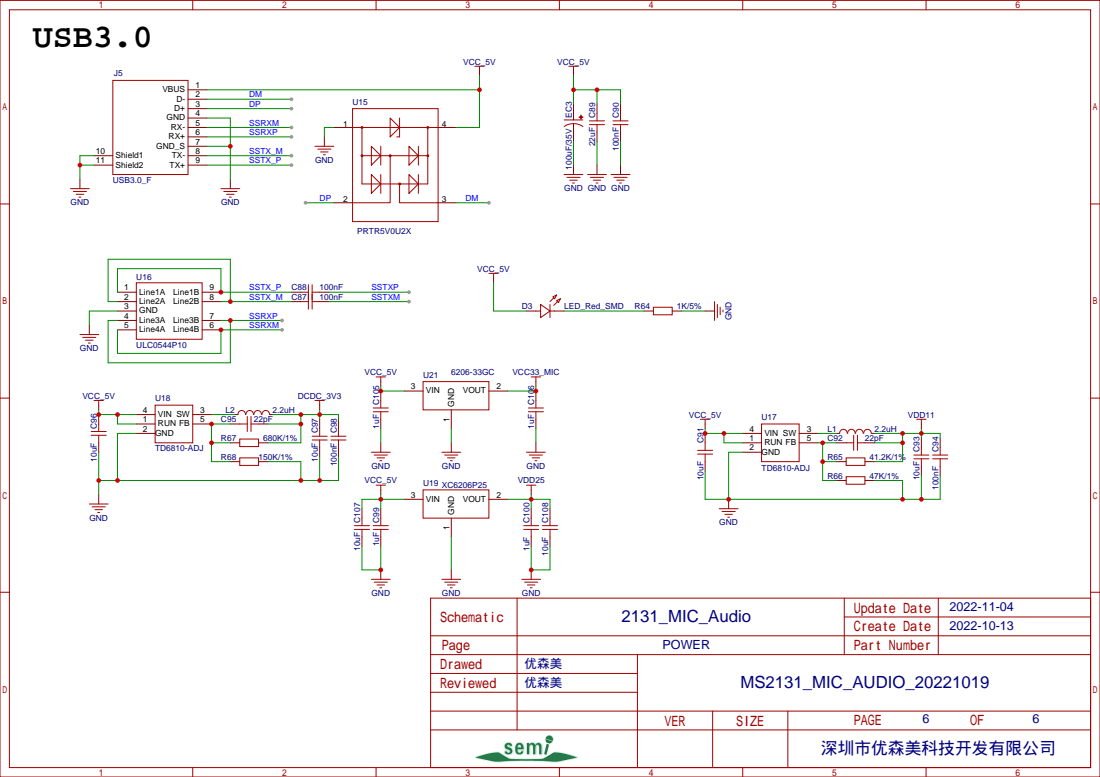
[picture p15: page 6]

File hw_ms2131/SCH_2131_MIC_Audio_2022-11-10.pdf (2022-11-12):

# HDMI_IN

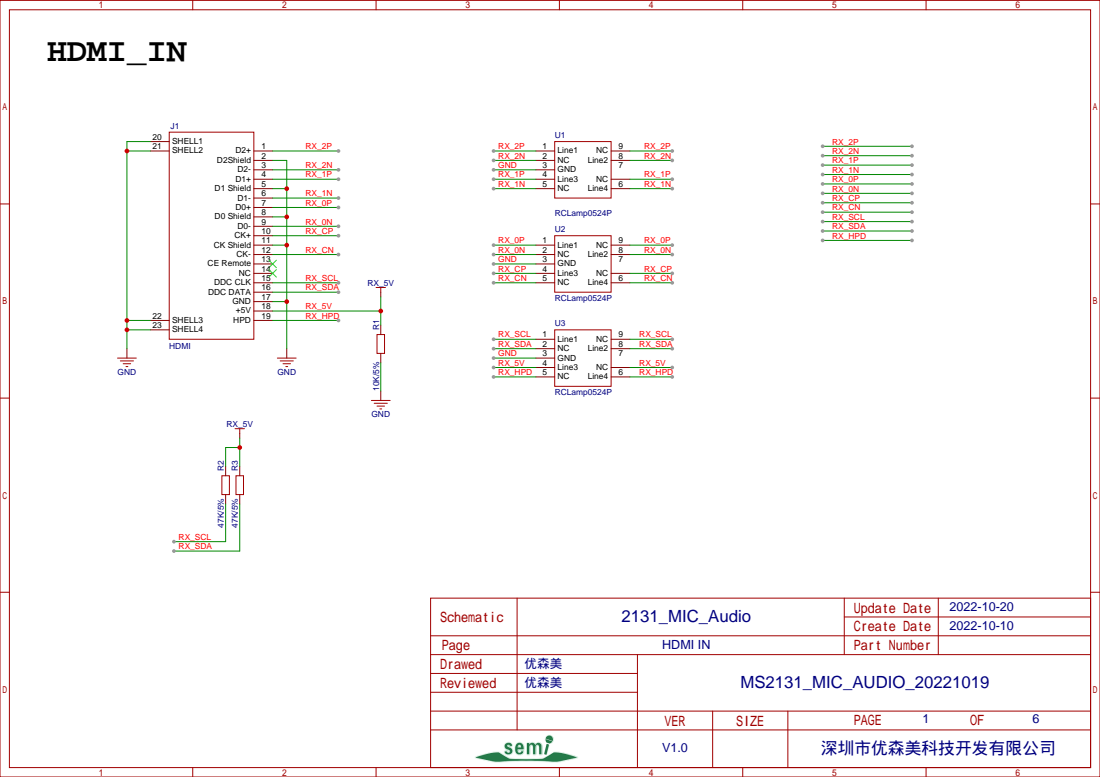
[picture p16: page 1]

MS2131

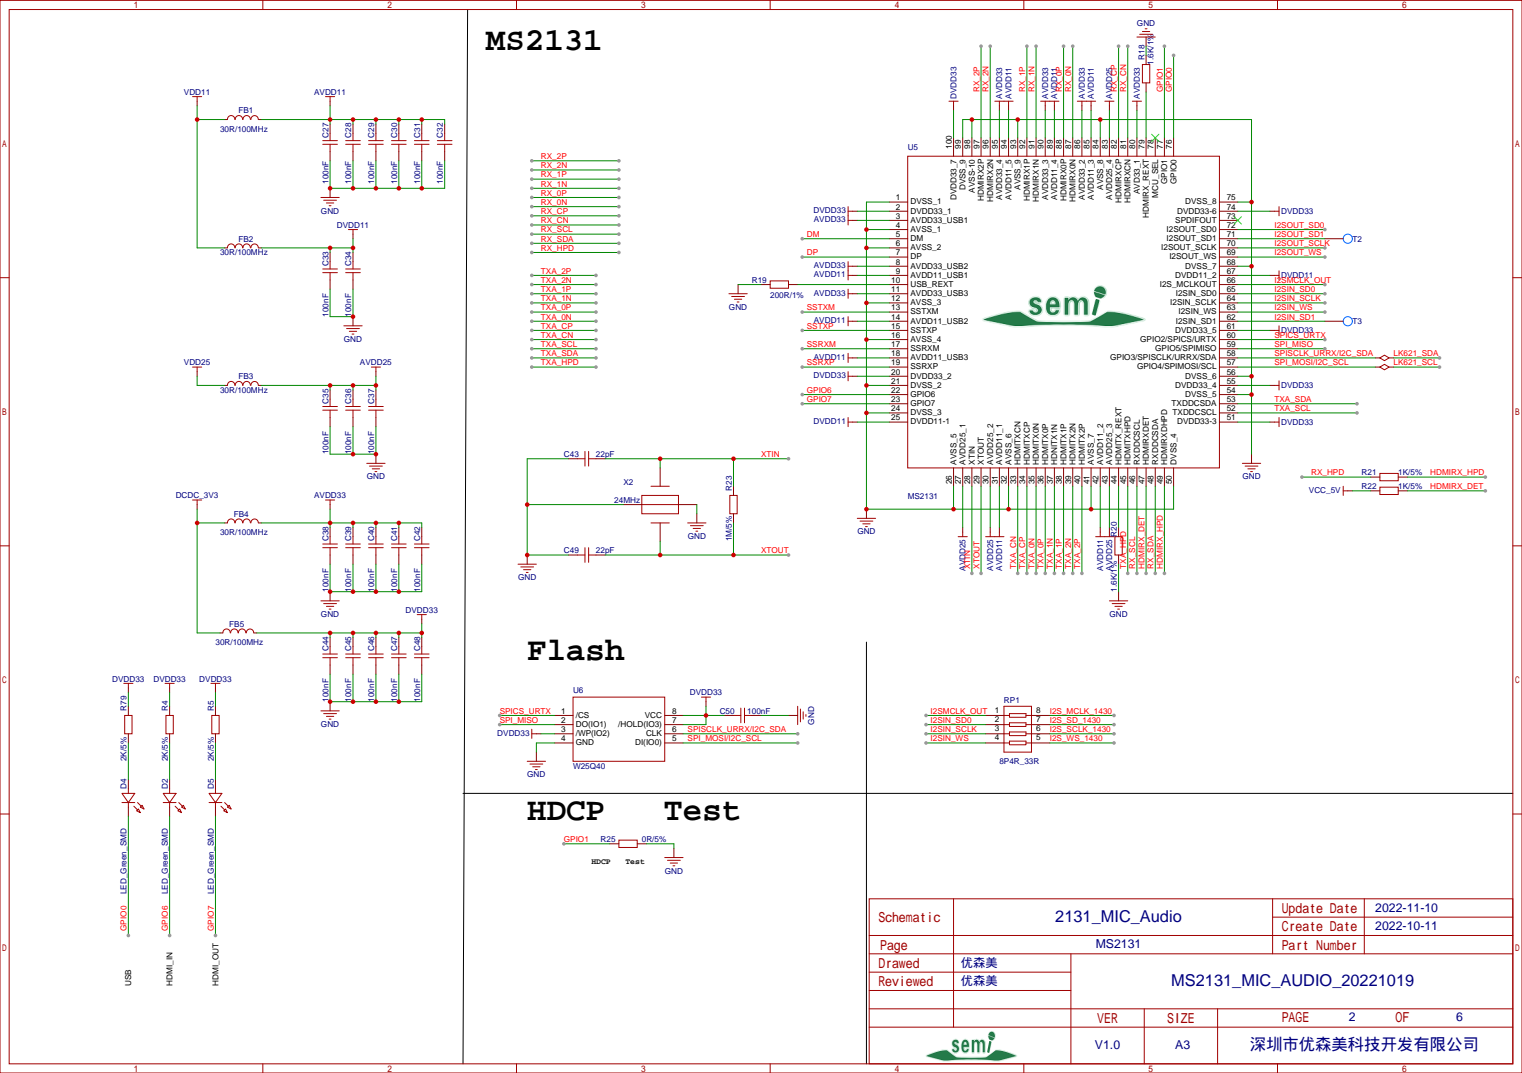
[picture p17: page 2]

# HDMI_OUT_B

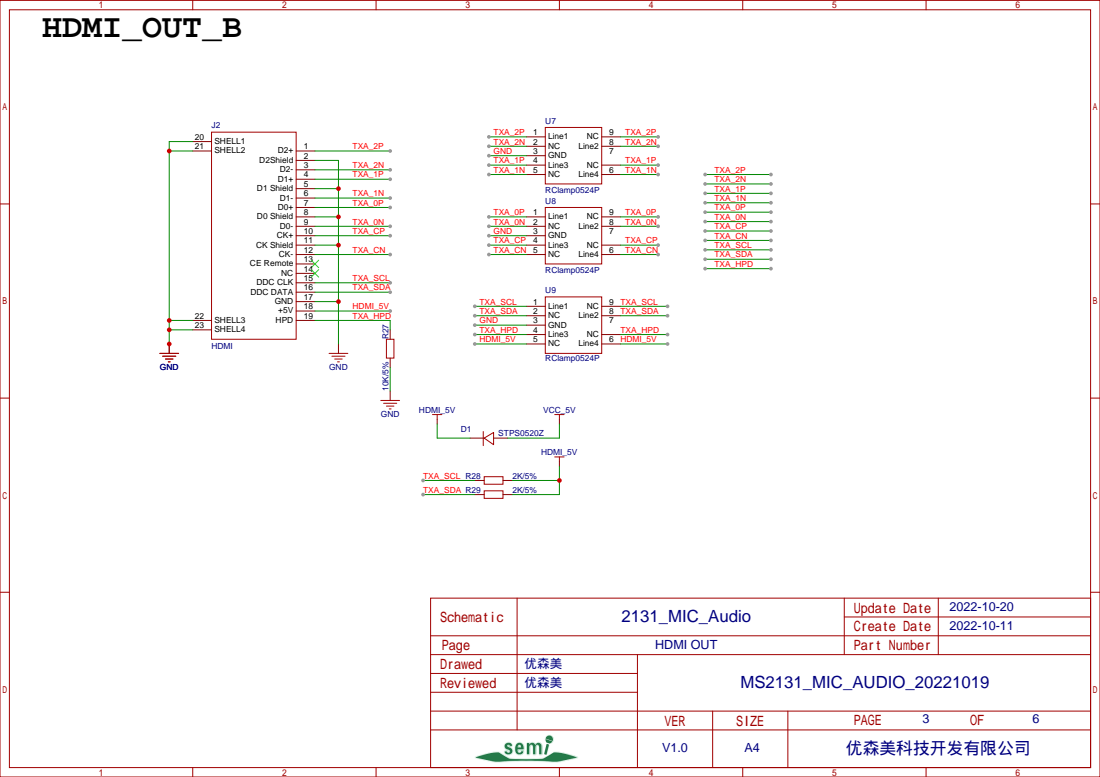
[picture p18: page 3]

# VCC33_MIC 100K/5% R³¹

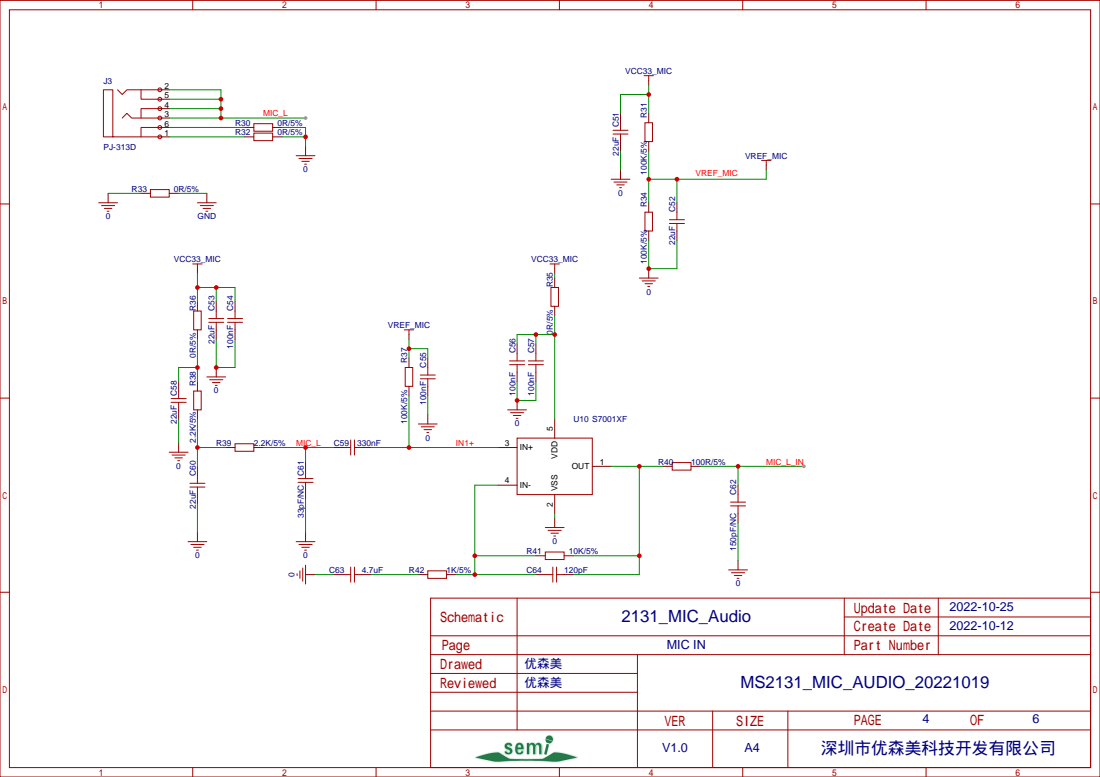
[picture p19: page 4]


# USB3.0


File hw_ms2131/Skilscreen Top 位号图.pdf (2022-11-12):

## MIC_IN

R49R54



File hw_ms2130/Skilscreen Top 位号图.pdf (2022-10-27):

C7C13
